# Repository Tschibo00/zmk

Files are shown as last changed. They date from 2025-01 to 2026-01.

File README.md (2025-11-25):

# zmk

## WARNING
This project is a personal project, i just built one prototype. It's not considered complete, nor tested or error-free.

I won't develop this much, just releasing it as-is for anybody knowledgable picking up and maybe building upon it.

It is NOT ready to take the files and produce a working keyboard!

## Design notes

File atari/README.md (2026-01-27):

# AtaKi
Wireless universal 40% keyboard in a 12x4U format, including mounting holes for BM40 cases and gaskets.
Will be using ZMK on a nice!nano

The PCB supports multiple configurations, including Katana with 0.5U indent and QAZ, also multiple bottow row configs are possible.
(almost) all switches are mounted sideways to have better stability with the overlapping footprints. Also it's no clearance problem with tested switches/caps and it supports the modified Selectric keycaps (see https://github.com/Tschibo00/qmk/tree/main/hacktrick for details on the idea)

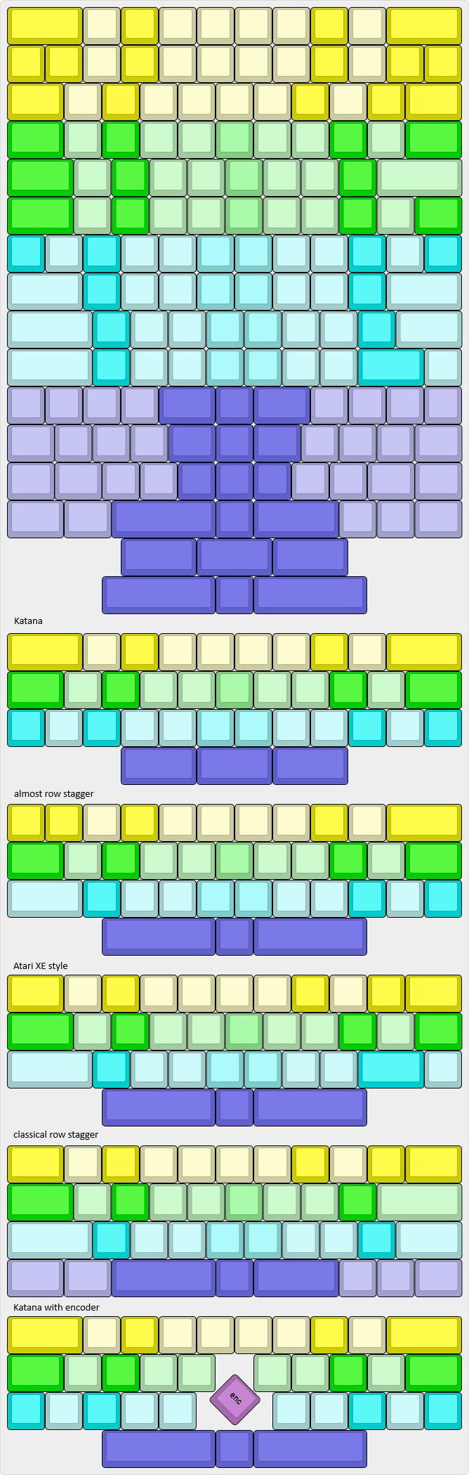
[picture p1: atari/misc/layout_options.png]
layout_options


## WARNING
This project is a personal project, i just built one prototype. It's not considered complete, nor tested or error-free.

I won't develop this much, just releasing it as-is for anybody knowledgable picking up and maybe building upon it.

It is NOT ready to take the files and produce a working keyboard!

## How to build
To not struggle when soldering, it should be done in the following order:
- solder all diodes (and resistor if equipped) first
- solder the two switches on opposite of MCU
  - if you want to put the MCU as low as possible, cut the pins of the switches first to sit quite flush with the PCB
- solder the MCU
  - put the short ends of the headers through the PCB, long end goes through the MCU
  - if you want to put the MCU flush down, solder headers to PCB first, then remove the spacers on the headers. Put MCU on and solder, clip headers
- solder remaining switches
  - triple-check with every row that your soldering the correct layout. put the required caps on the switches to see, which holes you need to solder to

# Todos
- [x] add PCB artwork
- [x] order the thing
- [x] hack firmware
- [ ] design Atari 130XE style case including function keys
- [ ] boast about it on r/mk
- [x] fix PCB (esp. encoder mount pads)
- [x] add note to U1 to put nano on bottom side
- [x] add traces to daughter board
- [x] add missing Atari footprints
- [x] move name+link to central bottom row, enlarge a bit
- [x] move reset switch because it's blocking the usb
- [x] add joystick ports
- [x] create base keymap
- [x] create additional keymaps, e.g. Katana
- [x] add LED connector

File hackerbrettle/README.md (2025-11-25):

# HackerBrettLe
Wireless split version of my usual keyboard layout, (more or less) migrated to ZMK.

34-key, gasket mount, mag-lock capable, using nice!nano

## WARNING
This project is a personal project, i just built one prototype. It's not considered complete, nor tested or error-free.

I won't develop this much, just releasing it as-is for anybody knowledgable picking up and maybe building upon it.

It is NOT ready to take the files and produce a working keyboard!

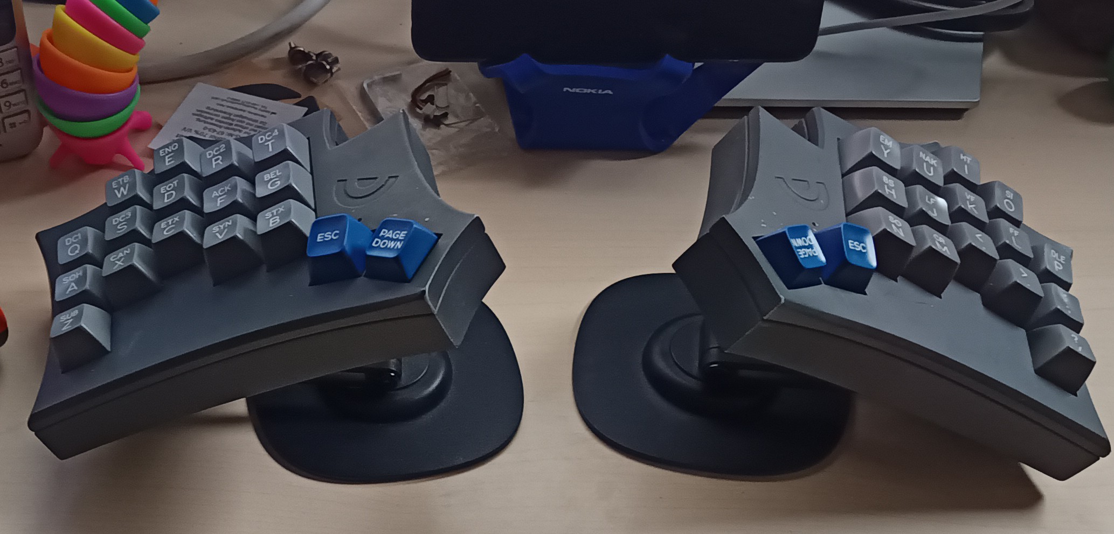
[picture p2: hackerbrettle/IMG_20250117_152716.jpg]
beauty shot


# Todos
- [x] fix shifted symbol layer keys
- [x] fix right GUI
- [x] check delay on longer strings (esp. execute-macros)
- [x] check HRM functionality
- [x] check mod-behaviour on thumb keys

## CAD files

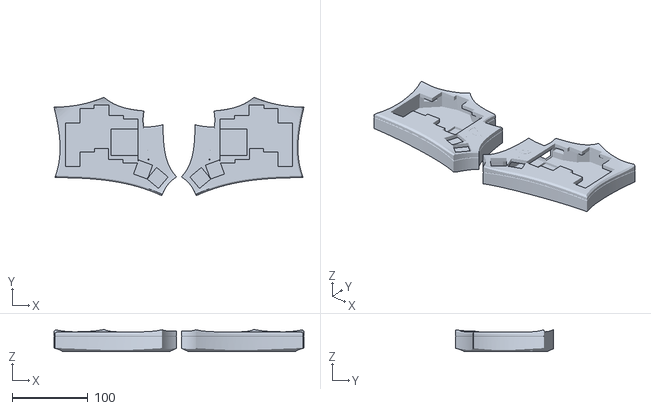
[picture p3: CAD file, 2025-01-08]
hackerbrettle/case/BrettLe v21.stl
330.0 x 129.9 x 29.3

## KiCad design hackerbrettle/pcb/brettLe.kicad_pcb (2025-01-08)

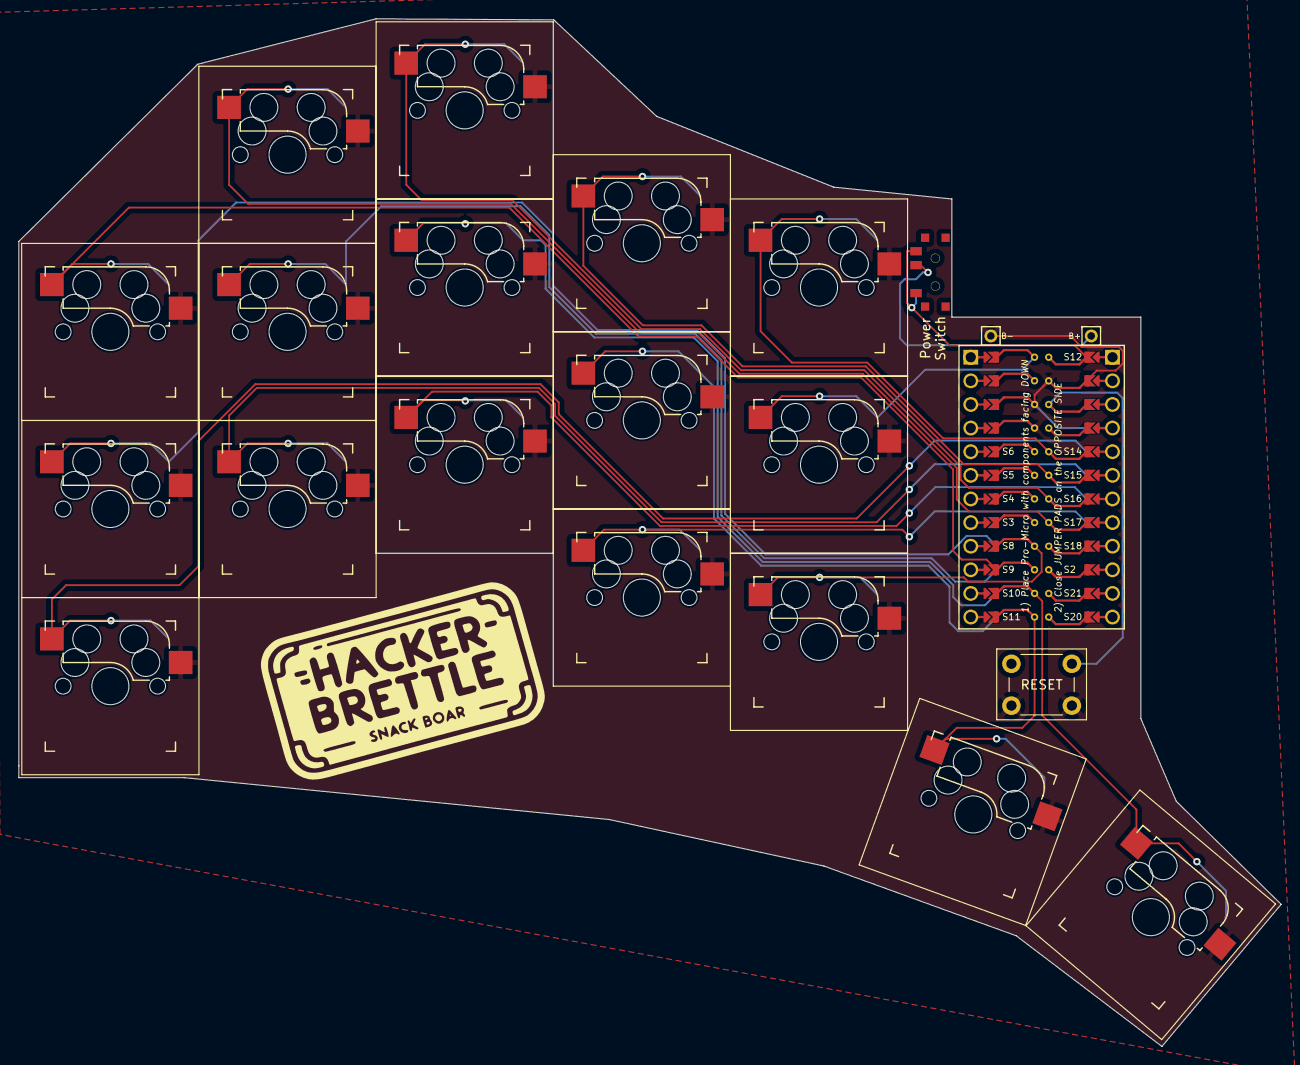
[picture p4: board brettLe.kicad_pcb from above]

Board: 2 copper layers, 135.7 x 110.5 mm, 23 parts (1 on the bottom side), 21 nets.

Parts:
Bat+r1: MountingHole_Pad; 1pin_conn
BatGND1: MountingHole_Pad; 1pin_conn
RST_B: SW_Push; SW_PUSH_6mm_H4.3mm
SW2, SW3, SW4, SW5, SW6, SW8, SW9, SW10, SW11, SW12, SW14, SW15, SW16, SW17, SW18, SW20, SW21: SW_Push; Kailh_socket_MX_reversible_sameside
SW_POWERR1: SW_SPDT; SPDT_C128955
SW_POWERR_BK: SW_SPDT; SPDT_C128955r
U1: ProMicro-kbd; ProMicro_facedown

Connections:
BT+_r: Bat+r1.1, SW_POWERR1.2 (B), SW_POWERR_BK.2
Switch1: SW2.1, U1.10
Switch2: SW3.1, U1.17
Switch3: SW4.1, U1.18
Switch4: SW5.1, U1.19
Switch5: SW6.1, U1.20
Switch6: SW8.1, U1.16
Switch7: SW9.1, U1.15
Switch8: SW10.1, U1.14
Switch9: SW11.1, U1.13
Switch10: SW12.1, U1.1
Switch11: SW14.1, U1.5
Switch12: SW15.1, U1.6
Switch13: SW16.1, U1.7
Switch14: SW17.1, U1.8
Switch15: SW18.1, U1.9
Switch16: SW21.1, U1.11
Switch17: SW20.1, U1.12
gnd: BatGND1.1, RST_B.1, SW2.2, SW3.2, SW4.2, SW5.2, SW6.2, SW8.2, SW9.2, SW10.2, SW11.2, SW12.2, SW14.2, SW15.2, SW16.2, SW17.2, SW18.2, SW20.2, SW21.2, U1.3, U1.4, U1.23
raw: SW_POWERR1.3 (C), SW_POWERR_BK.3, U1.24
reset: RST_B.2, U1.22

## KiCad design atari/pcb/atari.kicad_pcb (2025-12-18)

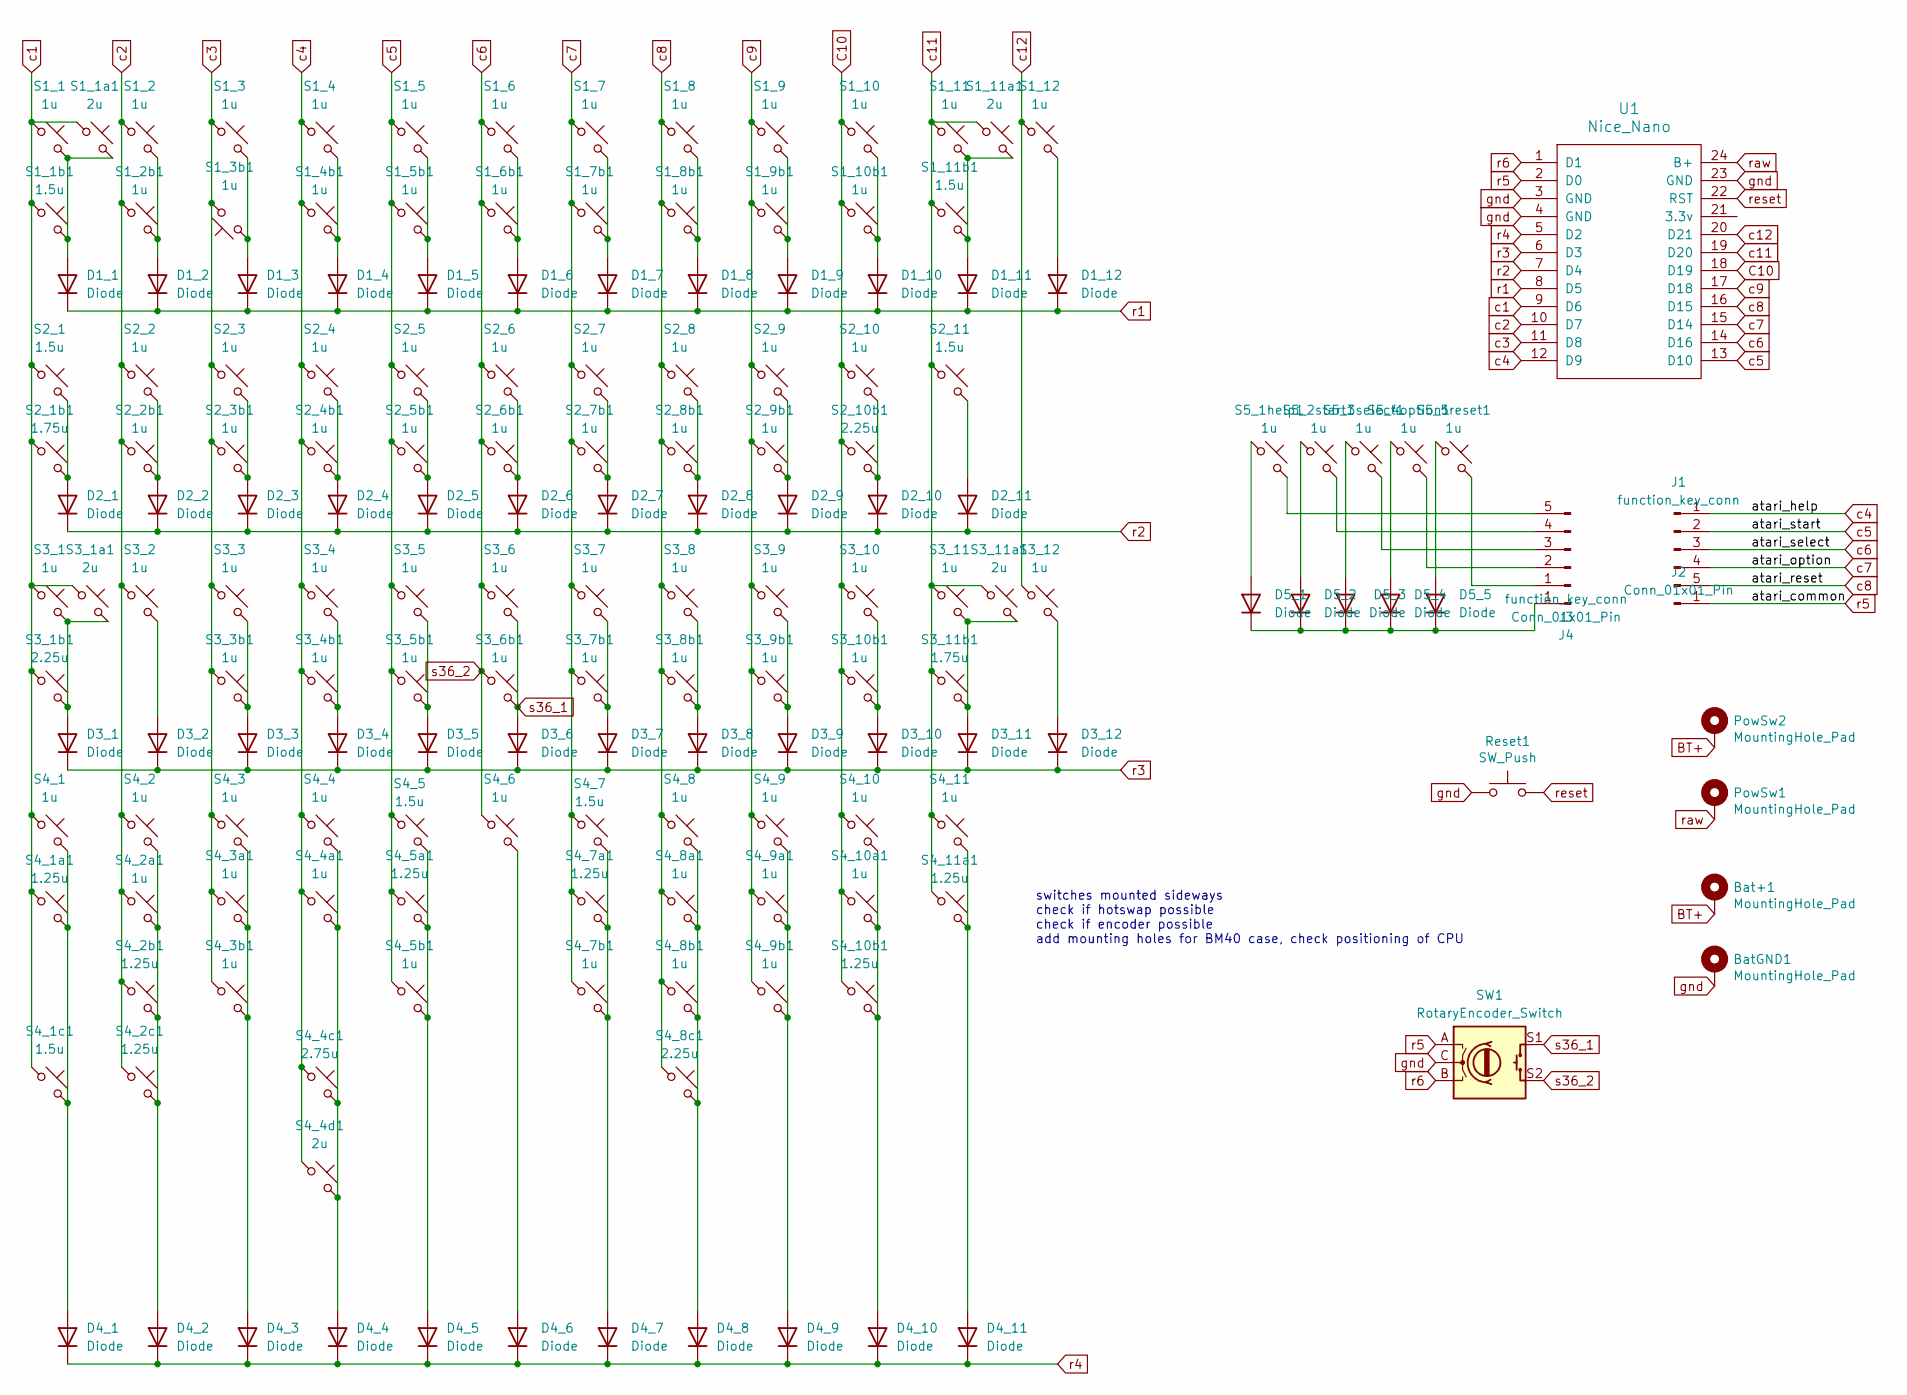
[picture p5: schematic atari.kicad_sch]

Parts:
Bat+1: MountingHole_Pad; SolderWire-0.5sqmm_1x01_D0.9mm_OD2.1mm
BatGND1: MountingHole_Pad; SolderWire-0.5sqmm_1x01_D0.9mm_OD2.1mm
D1_1, D1_2, D1_3, D1_4, D1_5, D1_6, D1_7, D1_8, D1_9, D1_10, D1_11, D1_12, D2_1, D2_2, D2_3, D2_4, D2_5, D2_6, D2_7, D2_8, D2_9, D2_10, D2_11, D3_1, D3_2, D3_3, D3_4, D3_5, D3_6, D3_7, D3_8, D3_9, D3_10, D3_11, D3_12, D4_1, D4_2, D4_3, D4_4, D4_5, D4_6, D4_7, D4_8, D4_9, D4_10, D4_11, D5_1, D5_2, D5_3, D5_4, D5_5: Diode; Diode_DO-35
J1, J3: function_key_conn; PinHeader_1x05_P2.54mm_Vertical
J2, J4: Conn_01x01_Pin; PinHeader_1x01_P2.54mm_Vertical
PowSw1, PowSw2: MountingHole_Pad; SolderWire-0.5sqmm_1x01_D0.9mm_OD2.1mm
Reset1: SW_Push; SW_PUSH_6mm_H4.3mm
S1_1, S1_2, S1_2b1, S1_3, S1_3b1, S1_4, S1_4b1, S1_5, S1_5b1, S1_6, S1_6b1, S1_7, S1_7b1, S1_8, S1_8b1, S1_9, S1_9b1, S1_10, S1_10b1, S1_11, S1_12, S2_2, S2_2b1, S2_3, S2_3b1, S2_4, S2_4b1, S2_5, S2_5b1, S2_6, S2_6b1, S2_7, S2_7b1, S2_8, S2_8b1, S2_9, S2_9b1, S2_10, S3_1, S3_2, S3_3, S3_3b1, S3_4, S3_4b1, S3_5, S3_5b1, S3_6, S3_6b1, S3_7, S3_7b1, S3_8, S3_8b1, S3_9, S3_9b1, S3_10, S3_10b1, S3_11, S3_12, S4_1, S4_2, S4_2a1, S4_3, S4_3a1, S4_3b1, S4_4, S4_4a1, S4_5b1, S4_6, S4_7b1, S4_8, S4_8a1, S4_8b1, S4_9, S4_9a1, S4_9b1, S4_10, S4_10a1, S4_11, S5_1help1, S5_2start1, S5_3select1, S5_4option1, S5_5reset1: 1u; MX_PCB_1.00u
S1_1a1, S1_11a1, S3_1a1, S3_11a1, S4_4d1: 2u; MX_PCB_2.00u_90deg
S1_1b1, S1_11b1, S2_1, S2_11, S4_1c1, S4_5, S4_7: 1.5u; MX_PCB_1.50u_90deg
S2_1b1, S3_11b1: 1.75u; MX_PCB_1.75u_90deg
S2_10b1, S3_1b1, S4_8c1: 2.25u; MX_PCB_2.25u_90deg
S4_1a1, S4_2b1, S4_2c1, S4_5a1, S4_7a1, S4_10b1, S4_11a1: 1.25u; MX_PCB_1.25u_90deg
S4_4c1: 2.75u; MX_PCB_2.75u_90deg
SW1: RotaryEncoder_Switch; RotaryEncoder_Alps_EC11E-Switch_Vertical_H20mm
U1: Nice_Nano; Nice_Nano_V2

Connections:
BT+: Bat+1.1, PowSw2.1; also elsewhere on the board
C10: S1_10.1, S1_10b1.1, S2_10.1, S2_10b1.1, S3_10.1, S3_10b1.1, S4_10.1, S4_10a1.1, S4_10b1.1, U1.18 (D19)
unnamed: D1_1.2 (A), S1_1.2, S1_1a1.2, S1_1b1.2
unnamed: D1_2.2 (A), S1_2.2, S1_2b1.2
unnamed: D1_3.2 (A), S1_3.2, S1_3b1.1
unnamed: D1_4.2 (A), S1_4.2, S1_4b1.2
unnamed: D1_5.2 (A), S1_5.2, S1_5b1.2
unnamed: D1_6.2 (A), S1_6.2, S1_6b1.2
unnamed: D1_7.2 (A), S1_7.2, S1_7b1.2
unnamed: D1_8.2 (A), S1_8.2, S1_8b1.2
unnamed: D1_9.2 (A), S1_9.2, S1_9b1.2
unnamed: D1_10.2 (A), S1_10.2, S1_10b1.2
unnamed: D1_11.2 (A), S1_11.2, S1_11a1.2, S1_11b1.2
unnamed: D1_12.2 (A), S1_12.2
unnamed: D2_1.2 (A), S2_1.2, S2_1b1.2
unnamed: D2_2.2 (A), S2_2.2, S2_2b1.2
unnamed: D2_3.2 (A), S2_3.2, S2_3b1.2
unnamed: D2_4.2 (A), S2_4.2, S2_4b1.2
unnamed: D2_5.2 (A), S2_5.2, S2_5b1.2
unnamed: D2_6.2 (A), S2_6.2, S2_6b1.2
unnamed: D2_7.2 (A), S2_7.2, S2_7b1.2
unnamed: D2_8.2 (A), S2_8.2, S2_8b1.2
unnamed: D2_9.2 (A), S2_9.2, S2_9b1.2
unnamed: D2_10.2 (A), S2_10.2, S2_10b1.2
unnamed: D2_11.2 (A), S2_11.2
unnamed: D3_1.2 (A), S3_1.2, S3_1a1.2, S3_1b1.2
unnamed: D3_2.2 (A), S3_2.2
unnamed: D3_3.2 (A), S3_3.2, S3_3b1.2
unnamed: D3_4.2 (A), S3_4.2, S3_4b1.2
unnamed: D3_5.2 (A), S3_5.2, S3_5b1.2
unnamed: D3_6.2 (A), S3_6.2, S3_6b1.2, SW1.S1
unnamed: D3_7.2 (A), S3_7.2, S3_7b1.2
unnamed: D3_8.2 (A), S3_8.2, S3_8b1.2
unnamed: D3_9.2 (A), S3_9.2, S3_9b1.2
unnamed: D3_10.2 (A), S3_10.2, S3_10b1.2
unnamed: D3_11.2 (A), S3_11.2, S3_11a1.2, S3_11b1.2
unnamed: D3_12.2 (A), S3_12.2
unnamed: D4_1.2 (A), S4_1.2, S4_1a1.2, S4_1c1.2
unnamed: D4_2.2 (A), S4_2.2, S4_2a1.2, S4_2b1.2, S4_2c1.2
unnamed: D4_3.2 (A), S4_3.2, S4_3a1.2, S4_3b1.2
unnamed: D4_4.2 (A), S4_4.2, S4_4a1.2, S4_4c1.2, S4_4d1.2
unnamed: D4_5.2 (A), S4_5.2, S4_5a1.2, S4_5b1.2
unnamed: D4_6.2 (A), S4_6.2
unnamed: D4_7.2 (A), S4_7.2, S4_7a1.2, S4_7b1.2
unnamed: D4_8.2 (A), S4_8.2, S4_8a1.2, S4_8b1.2, S4_8c1.2
unnamed: D4_9.2 (A), S4_9.2, S4_9a1.2, S4_9b1.2
unnamed: D4_10.2 (A), S4_10.2, S4_10a1.2, S4_10b1.2
unnamed: D4_11.2 (A), S4_11.2, S4_11a1.2
unnamed: D5_1.1 (K), D5_2.1 (K), D5_3.1 (K), D5_4.1 (K), D5_5.1 (K), J4.1
unnamed: D5_1.2 (A), S5_1help1.1
unnamed: D5_2.2 (A), S5_2start1.1
unnamed: D5_3.2 (A), S5_3select1.1
unnamed: D5_4.2 (A), S5_4option1.1
unnamed: D5_5.2 (A), S5_5reset1.1
unnamed: J2.1, SW1.A, U1.2 (D0)
unnamed: J3.1, S5_5reset1.2
unnamed: J3.2, S5_4option1.2
unnamed: J3.3, S5_3select1.2
unnamed: J3.4, S5_2start1.2
unnamed: J3.5, S5_1help1.2
unnamed: SW1.B, U1.1 (D1)
c1: S1_1.1, S1_1a1.1, S1_1b1.1, S2_1.1, S2_1b1.1, S3_1.1, S3_1a1.1, S3_1b1.1, S4_1.1, S4_1a1.1, S4_1c1.1, U1.9 (D6)
c2: S1_2.1, S1_2b1.1, S2_2.1, S2_2b1.1, S3_2.1, S4_2.1, S4_2a1.1, S4_2b1.1, S4_2c1.1, U1.10 (D7)
c3: S1_3.1, S1_3b1.2, S2_3.1, S2_3b1.1, S3_3.1, S3_3b1.1, S4_3.1, S4_3a1.1, S4_3b1.1, U1.11 (D8)
c4: J1.1, S1_4.1, S1_4b1.1, S2_4.1, S2_4b1.1, S3_4.1, S3_4b1.1, S4_4.1, S4_4a1.1, S4_4c1.1, S4_4d1.1, U1.12 (D9)
c5: J1.2, S1_5.1, S1_5b1.1, S2_5.1, S2_5b1.1, S3_5.1, S3_5b1.1, S4_5.1, S4_5a1.1, S4_5b1.1, U1.13 (D10)
c6: J1.3, S1_6.1, S1_6b1.1, S2_6.1, S2_6b1.1, S3_6.1, S3_6b1.1, S4_6.1, SW1.S2, U1.14 (D16)
c7: J1.4, S1_7.1, S1_7b1.1, S2_7.1, S2_7b1.1, S3_7.1, S3_7b1.1, S4_7.1, S4_7a1.1, S4_7b1.1, U1.15 (D14)
c8: J1.5, S1_8.1, S1_8b1.1, S2_8.1, S2_8b1.1, S3_8.1, S3_8b1.1, S4_8.1, S4_8a1.1, S4_8b1.1, S4_8c1.1, U1.16 (D15)
c9: S1_9.1, S1_9b1.1, S2_9.1, S2_9b1.1, S3_9.1, S3_9b1.1, S4_9.1, S4_9a1.1, S4_9b1.1, U1.17 (D18)
c11: S1_11.1, S1_11a1.1, S1_11b1.1, S2_11.1, S3_11.1, S3_11a1.1, S3_11b1.1, S4_11.1, S4_11a1.1, U1.19 (D20)
c12: S1_12.1, S3_12.1, U1.20 (D21)
gnd: BatGND1.1, Reset1.1, SW1.C, U1.3 (GND), U1.4 (GND), U1.23 (GND); also elsewhere on the board
r1: D1_1.1 (K), D1_2.1 (K), D1_3.1 (K), D1_4.1 (K), D1_5.1 (K), D1_6.1 (K), D1_7.1 (K), D1_8.1 (K), D1_9.1 (K), D1_10.1 (K), D1_11.1 (K), D1_12.1 (K), U1.8 (D5)
r2: D2_1.1 (K), D2_2.1 (K), D2_3.1 (K), D2_4.1 (K), D2_5.1 (K), D2_6.1 (K), D2_7.1 (K), D2_8.1 (K), D2_9.1 (K), D2_10.1 (K), D2_11.1 (K), U1.7 (D4)
r3: D3_1.1 (K), D3_2.1 (K), D3_3.1 (K), D3_4.1 (K), D3_5.1 (K), D3_6.1 (K), D3_7.1 (K), D3_8.1 (K), D3_9.1 (K), D3_10.1 (K), D3_11.1 (K), D3_12.1 (K), U1.6 (D3)
r4: D4_1.1 (K), D4_2.1 (K), D4_3.1 (K), D4_4.1 (K), D4_5.1 (K), D4_6.1 (K), D4_7.1 (K), D4_8.1 (K), D4_9.1 (K), D4_10.1 (K), D4_11.1 (K), U1.5 (D2)
raw: PowSw1.1, U1.24 (B+)
reset: Reset1.2, U1.22 (RST)

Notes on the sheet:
switches mounted sideways check if hotswap possible check if encoder possible add mounting holes for BM40 case, check positioning of CPU

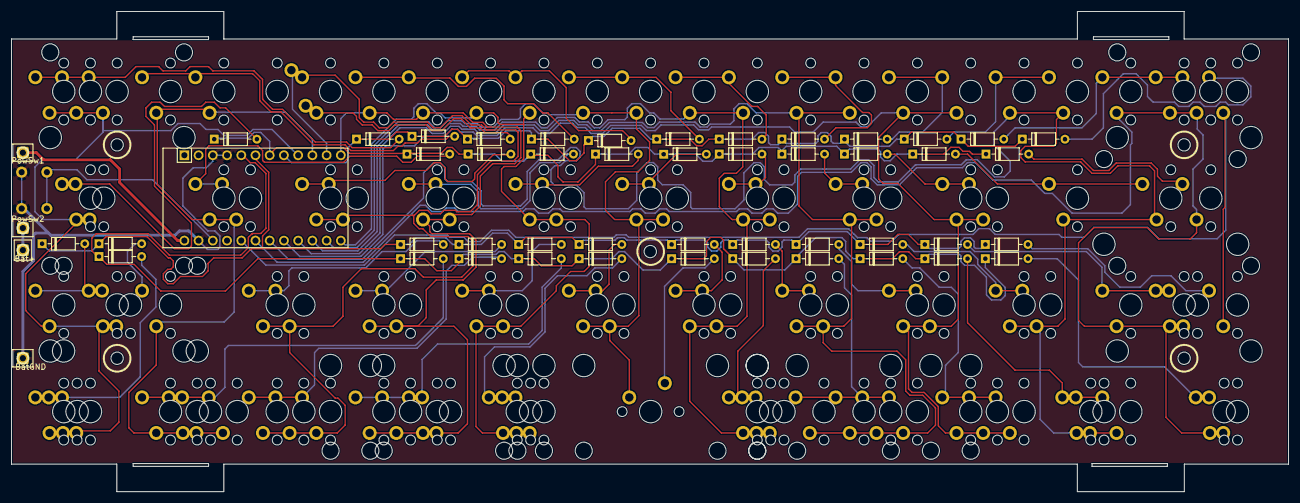
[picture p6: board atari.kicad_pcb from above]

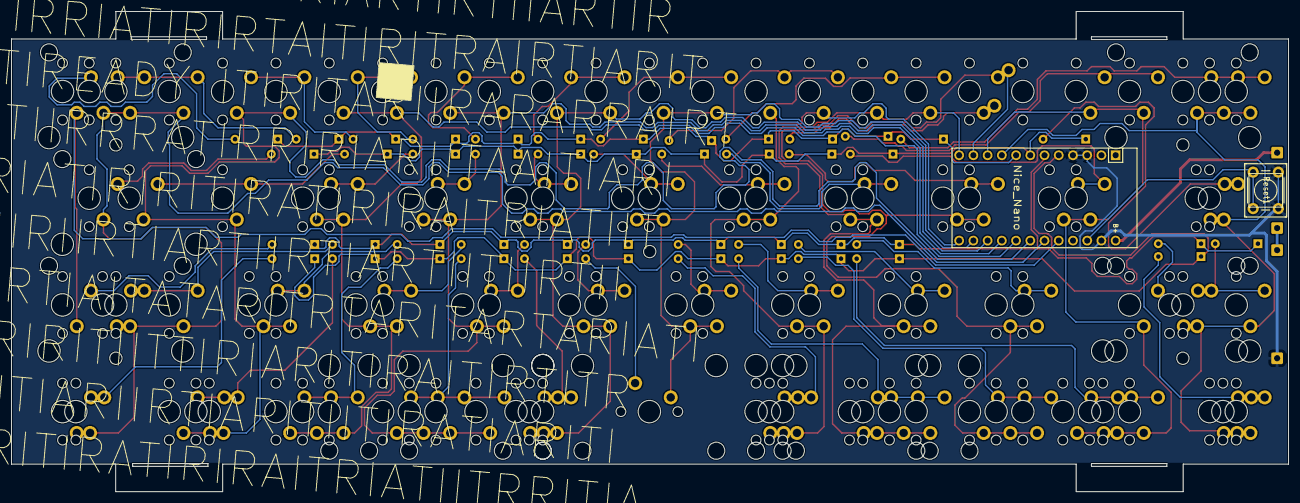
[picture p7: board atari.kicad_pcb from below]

Board: 2 copper layers, 228.0 x 85.7 mm, 155 parts (2 on the bottom side), 66 nets.

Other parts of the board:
Bat+: MountingHole_Pad; SolderWire-0.5sqmm_1x01_D0.9mm_OD2.1mm
BatGND: MountingHole_Pad; SolderWire-0.5sqmm_1x01_D0.9mm_OD2.1mm

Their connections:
BT+: Bat+.1; also elsewhere on the board
gnd: BatGND.1; also elsewhere on the board

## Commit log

2025-12-16 moved diodes in; cleanup; fixed fill
    [atari.kicad_pcb, atari.kicad_sch]
2025-12-17 cleanup; fill remaining holes where possible
    [atari.kicad_pcb]
2025-12-18 more cleanup; optimizing fill ratio
    [atari.kicad_pcb]
2025-12-24 added function key breakoff
    [atari.kicad_sch]
2025-12-26 added optional encoder
    [atari.kicad_sch]
2026-01-27 initial version of updated design
    - added joystick port
    - made switch alignment consistent
    - fixed missing traces
    - moved reset button away from USB port
    - added LED connector
    - removed option buttons daughterboard (see v1 for that)
    [atari.kicad_sch]
2026-01-27 moved to v1 subfolder
    [atari.kicad_sch]
2026-01-27 fixed issues, added production file
    [atari.kicad_sch]
